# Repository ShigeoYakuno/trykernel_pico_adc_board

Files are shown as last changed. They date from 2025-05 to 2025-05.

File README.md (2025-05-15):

# 基板概要

## 全体



## 表面



## 裏面



## 3Dおもて



## 3D うら



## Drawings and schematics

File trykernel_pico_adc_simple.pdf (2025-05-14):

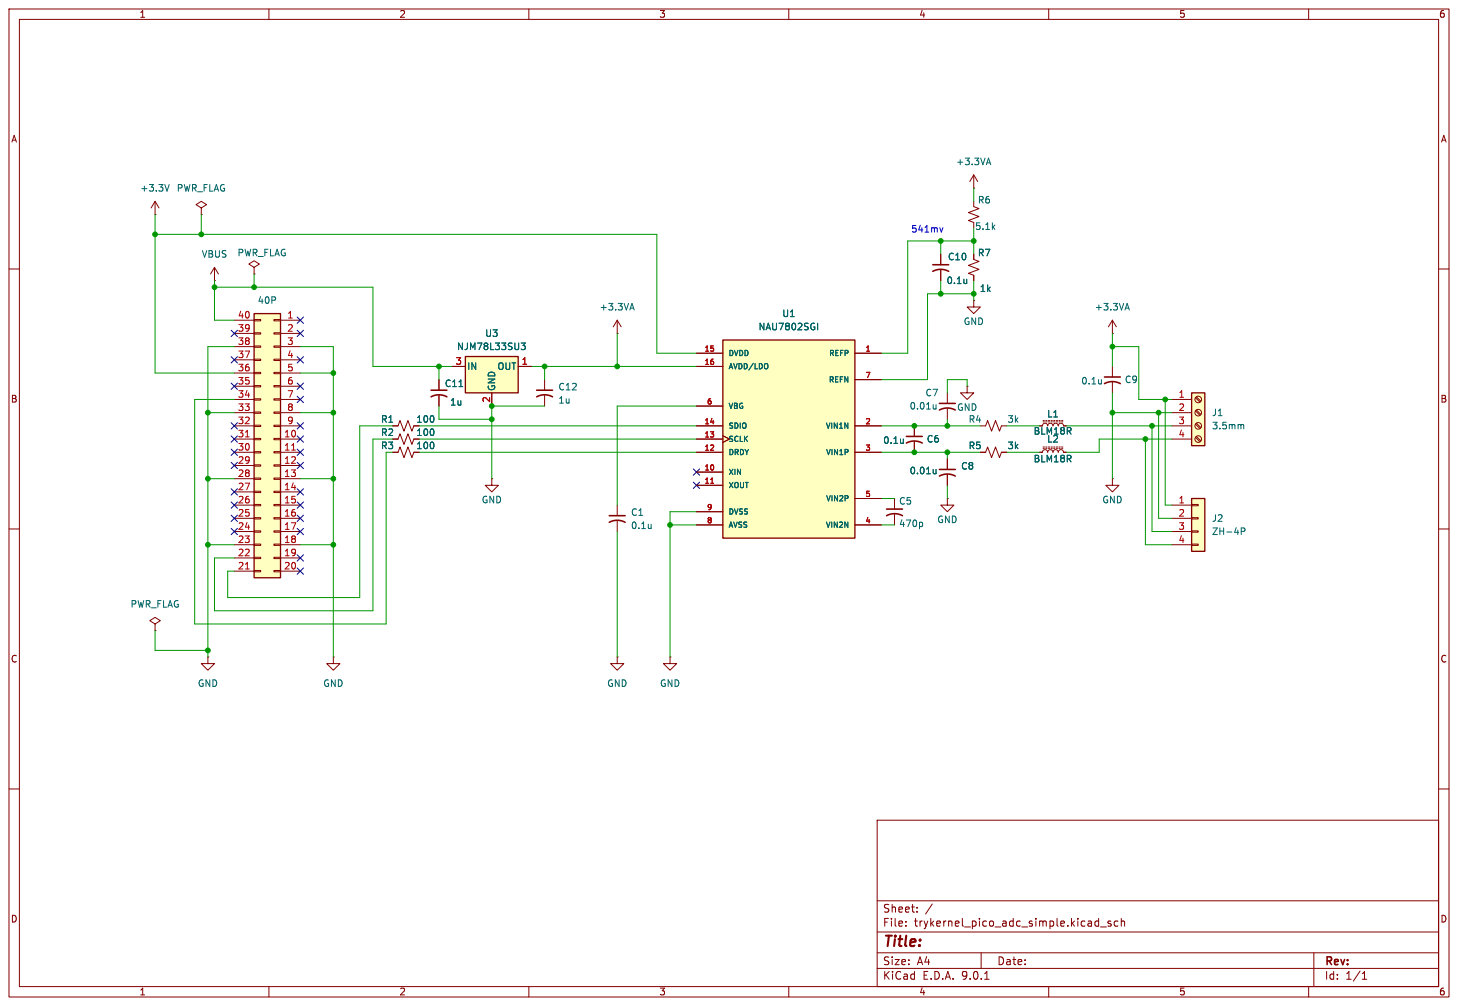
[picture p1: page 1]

Id: 1/1 Title: File: trykernel_pico_adc_simple.kicad_sch Sheet: / GND

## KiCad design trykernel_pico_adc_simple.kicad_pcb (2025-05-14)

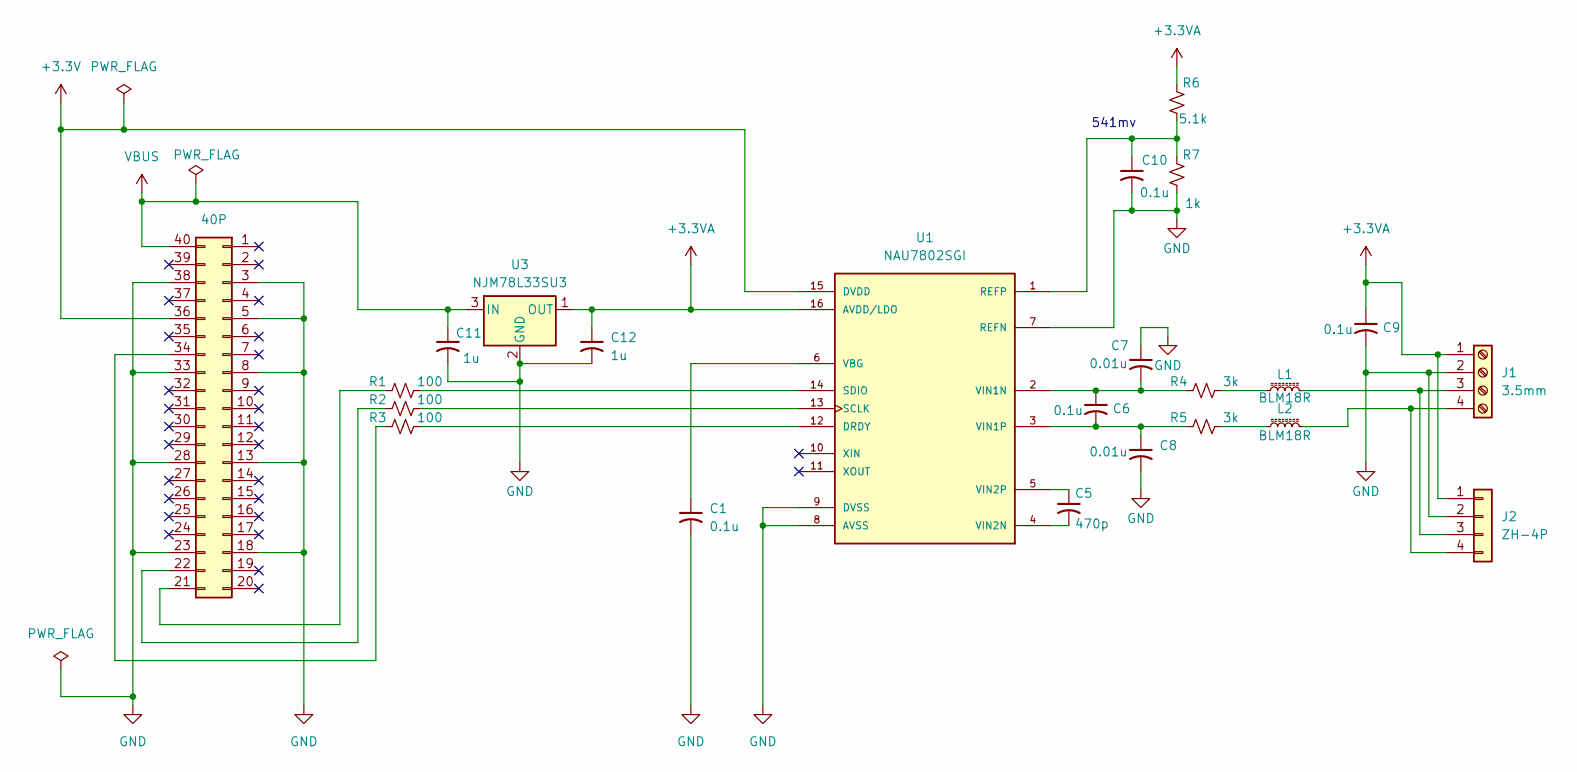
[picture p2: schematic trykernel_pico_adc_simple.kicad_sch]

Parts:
C1, C6, C9, C10: 0.1u; C_0603_1608Metric_Pad1.08x0.95mm_HandSolder
C5: 470p; C_0603_1608Metric_Pad1.08x0.95mm_HandSolder
C7, C8: 0.01u; C_0603_1608Metric_Pad1.08x0.95mm_HandSolder
C11, C12: 1u; C_0603_1608Metric_Pad1.08x0.95mm_HandSolder
J1: 3.5mm; TerminalBlock_4Ucon_1x04_P3.50mm_Horizontal
J2: ZH-4P; JST_ZH_B4B-ZR_1x04_P1.50mm_Vertical
J7: 40P; RPI_Hat_B+
L1, L2: BLM18R; R_0603_1608Metric_Pad0.98x0.95mm_HandSolder
R1, R2, R3: 100; R_0603_1608Metric_Pad0.98x0.95mm_HandSolder
R4, R5: 3k; R_0603_1608Metric_Pad0.98x0.95mm_HandSolder
R6: 5.1k; R_0603_1608Metric_Pad0.98x0.95mm_HandSolder
R7: 1k; R_0603_1608Metric_Pad0.98x0.95mm_HandSolder
U1: NAU7802SGI; SOIC127P600X175-16N; PARTREV 2.6
U3: NJM78L33SU3; SOT-89-3

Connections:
+3.3V: J7.36, U1.15 (DVDD)
+3.3VA: C9.1, C12.1, J1.1, J2.1, R6.2, U1.16 (AVDD/LDO), U3.1 (OUT)
GND: C1.2, C7.1, C8.2, C9.2, C10.2, C11.2, C12.2, J1.2, J2.2, J7.3, J7.5, J7.8, J7.13, J7.18, J7.23, J7.28, J7.33, J7.38, R7.1, U1.7 (REFN), U1.8 (AVSS), U1.9 (DVSS), U3.2 (GND)
unnamed: J1.3, J2.3, L1.2
unnamed: J1.4, J2.4, L2.2
unnamed: J7.21, R1.1
unnamed: J7.22, R2.1
unnamed: J7.34, R3.1
unnamed: L1.1, R4.2
unnamed: L2.1, R5.2
unnamed: R3.2, U1.12 (DRDY)
unnamed: C10.1, R6.1, R7.2, U1.1 (REFP)
unnamed: R2.2, U1.13 (SCLK)
unnamed: R1.2, U1.14 (SDIO)
unnamed: C1.1, U1.6 (VBG)
unnamed: C6.1, C7.2, R4.1, U1.2 (VIN1N)
unnamed: C6.2, C8.1, R5.1, U1.3 (VIN1P)
unnamed: C5.2, U1.4 (VIN2N)
unnamed: C5.1, U1.5 (VIN2P)
VBUS: C11.1, J7.40, U3.3 (IN)

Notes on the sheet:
541mv

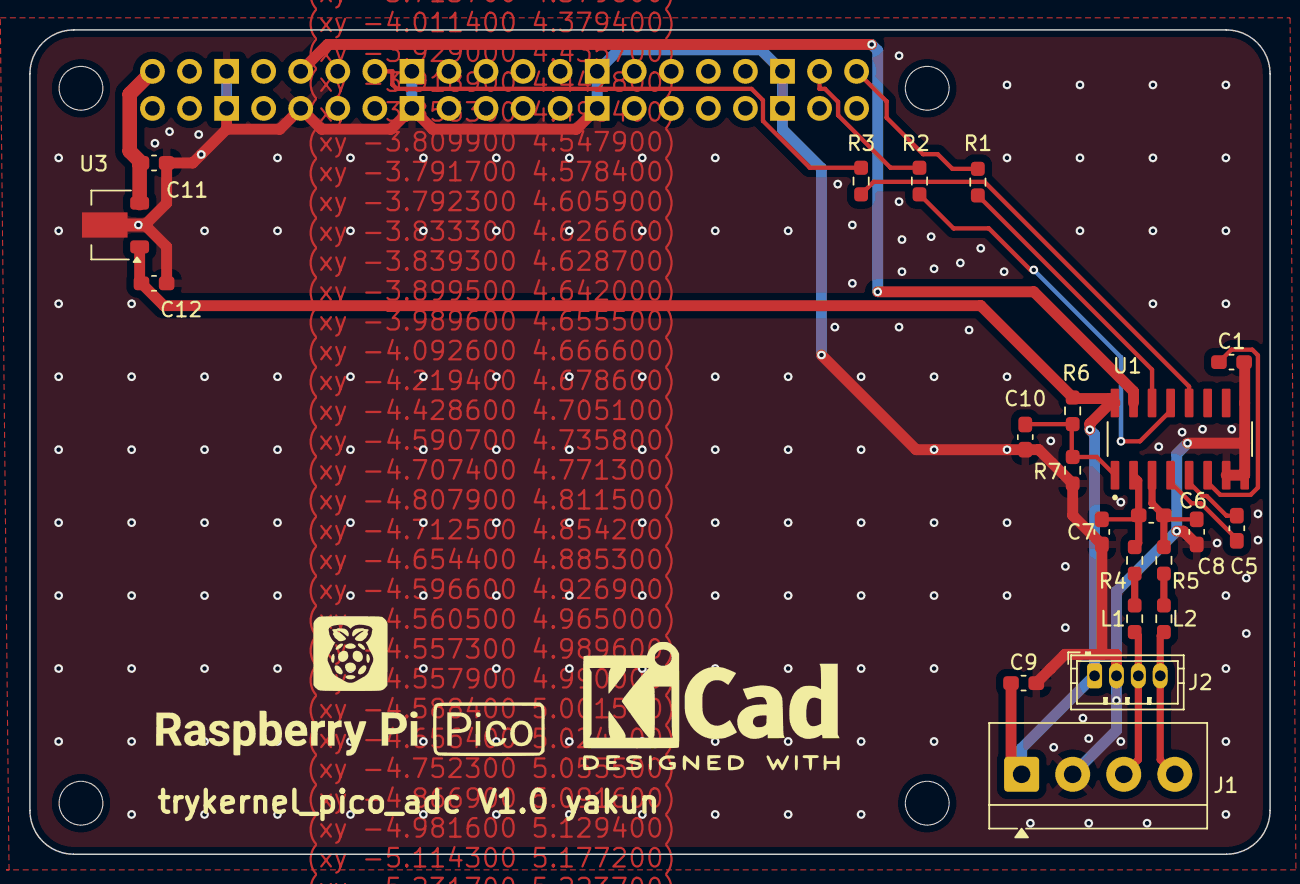
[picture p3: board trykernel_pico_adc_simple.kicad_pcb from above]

Board: 2 copper layers, 85.0 x 56.5 mm, 23 parts (0 on the bottom side), 20 nets.

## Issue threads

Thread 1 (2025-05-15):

基板の説明

ShigeoYakuno, 2025-05-15:
# trykernel pico　ADCボード

## ADC選定
- 市販ADCの入手性から、下記の3つに絞った
- HX711は通信方式が疑似SPIでpicoで未対応のインタフェースだった
- ビッドバンギングで疑似SPIを作るとオーバヘッド大きいので採用を見送った
- あとはコストとのバランスでNAU7802を採用した。

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

## NAU7802 TIPS
- データシートより以下の2点の注意点が分かった
-
1. AVDDはDVDDを上回ってはいけない
2. I2Cの電圧(DVDD)は、接続するマイコンと同じ電圧を推奨する

- マイコンはpicoなので、DVDDは3.3Vとした。
- AVDDも3.3V以下の縛りの中、なるべく出力を大きくしたいので、3.3Vとした。
- 2番目はI2Cラインだけの問題なので、レベルシフタ回路を使えば解決できそうではあるが、、3.7Vリポバッテリーでの駆動を考えているので、素直にLDOを介して3.3Vに落として使うことにした。
- チャージポンプ(倍電圧回路)で3.7V➡7.4Vに変換し、I2Cラインはレベルシフタを搭載し、AVDDとDVDDを5V系で構成する案も考えたが、まずはシンプルな案で様子見をする。

## アナログ回路部
- DVDDとAVDDは同じ3.3Vだが攻勢を分ける。DVDDはpico内蔵の電源から供給される3.3Vを使う
- AVDDはノイズ影響を懸念して、3.7VからLDOで3.3Vを作る
- リファレンス回路とセンサの差動入力回路をAVDDから構成電圧が変動しても追従するように設計(レシオメトリック)

### リファレンス回路

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

- 精密金属皮膜抵抗(誤差1%)使用。
- 3.3Vから分圧で541mVをFSRとする。
- コンデンサもC0G特性を使用する。

### アンチエイリアス回路
- fcは380Hzで設計

- 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

- NAU7802のOSRが分からないが、FMOD=200kHzと見積もってナイキスト周波数(100KHz)で50dB付近まで落ちる計算

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

### デジタルフィルタ

- NAU7802の最高レート320SPSの設定で変換し、後段のソフト処理で64TAPのフィルタを設計する

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

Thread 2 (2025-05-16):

アナログ部電源

ShigeoYakuno, 2025-05-16:
## レギュレータを NJM78L33SU3からLDOタイプの変更

-当初選定していたNJM78L33SがVdoが1.5Vあり、3.7Vから3.3Vが作れないことに気づく...
- 同じ秋月で購入できるレギュレータで、LDOタイプを探した。

- 新しく選定したXC6202P332 はSOT-89のフルコンパチでVdoは最大280mV。これなら使えそう。(Iout=30mAのとき)
-
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
